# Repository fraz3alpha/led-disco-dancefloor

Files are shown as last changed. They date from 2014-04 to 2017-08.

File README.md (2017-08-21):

# led-disco-dancefloor

Welcome to the LED Disco Dance Floor project!

As seen at:

- Oggcamp 2017
- LJC Mad Scientists 2016

## Overview

The dancefloor project was conceived, as all good ideas are, at the pub.
The plan was to create a fully illuminated dancefloor, as a surpise, for the
wedding of two of my good friends; Gav & Anna.

The timeline from conception (pub) to completion (wedding) was roughly 8 months
between July of 2013 and the wedding in February 2014. Ideas were bounced around,
rejected, reworked, costed, rejected, reworked, and reworked some more over the
summer, and construction began in earnest November, and continued for 3 solid
months.

The result was a dancefloor consisting of 432 illuminated tiles, each 6"x6" (
because wood comes in feet and inches) creating an usable dancing area of 12'x9'.
The dancefloor was split into 9 modules (for transportation reasons), each coming
in at 4'x3' and about 15kg.

Patterns were created via a connected laptop via the included python program
to be displayed on each module by an ATMega328 microcontroller & TLC5940 constant
current LED drivers.

## The Software

The python software is available in `software/controller/`, and can be run with
or without an attached dancefloor for demonstration and testing purposes.

The software makes use of the **pygame** library to read input from connected joypads
and keyboards, as well as draw the GUI and handle the framerate. If a dancefloor
is connected, **pyserial** is used to send the data at 1Mbps

## The PCB & Firmware

The PCB is relatively simple and is only concerned with the action of parsing
incoming data via a serial connection and displaying it on the 48 connected RGB
LEDs. An ATMega328 is used as the microcontroller, and 3xTLC5940 ICs are used
to drive 16 LEDs each. Each of the Red, Green, and Blue LEDs are strobed, and
the switching is handled via 3 p-channel MOSFETs.

The firmware is written to be flashed using the Arduino IDE for convenience, but
uses very few of the Arduino library convenience functions (`random()`, which is
used in the failsafe backup pattern, being the exception) as most of the tight
loop is highly optimised for speed.

## Power

The entire dancefloor runs off 5v, and requires a high current power supply -
roughly 2.5A per module. An old ATX power supply with all the 5v rails tied
together has proved very reliable.

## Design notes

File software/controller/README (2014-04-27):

To start the controller code run `python DDRPi.py`

To start it in test mode with no floor attached and no need to sort out a config file run with '--testmode'

To run with a specific plugin for testing/development purposes, specify it with --plugin, e.g. : --plugin=HlsTestVisualisationPlugin

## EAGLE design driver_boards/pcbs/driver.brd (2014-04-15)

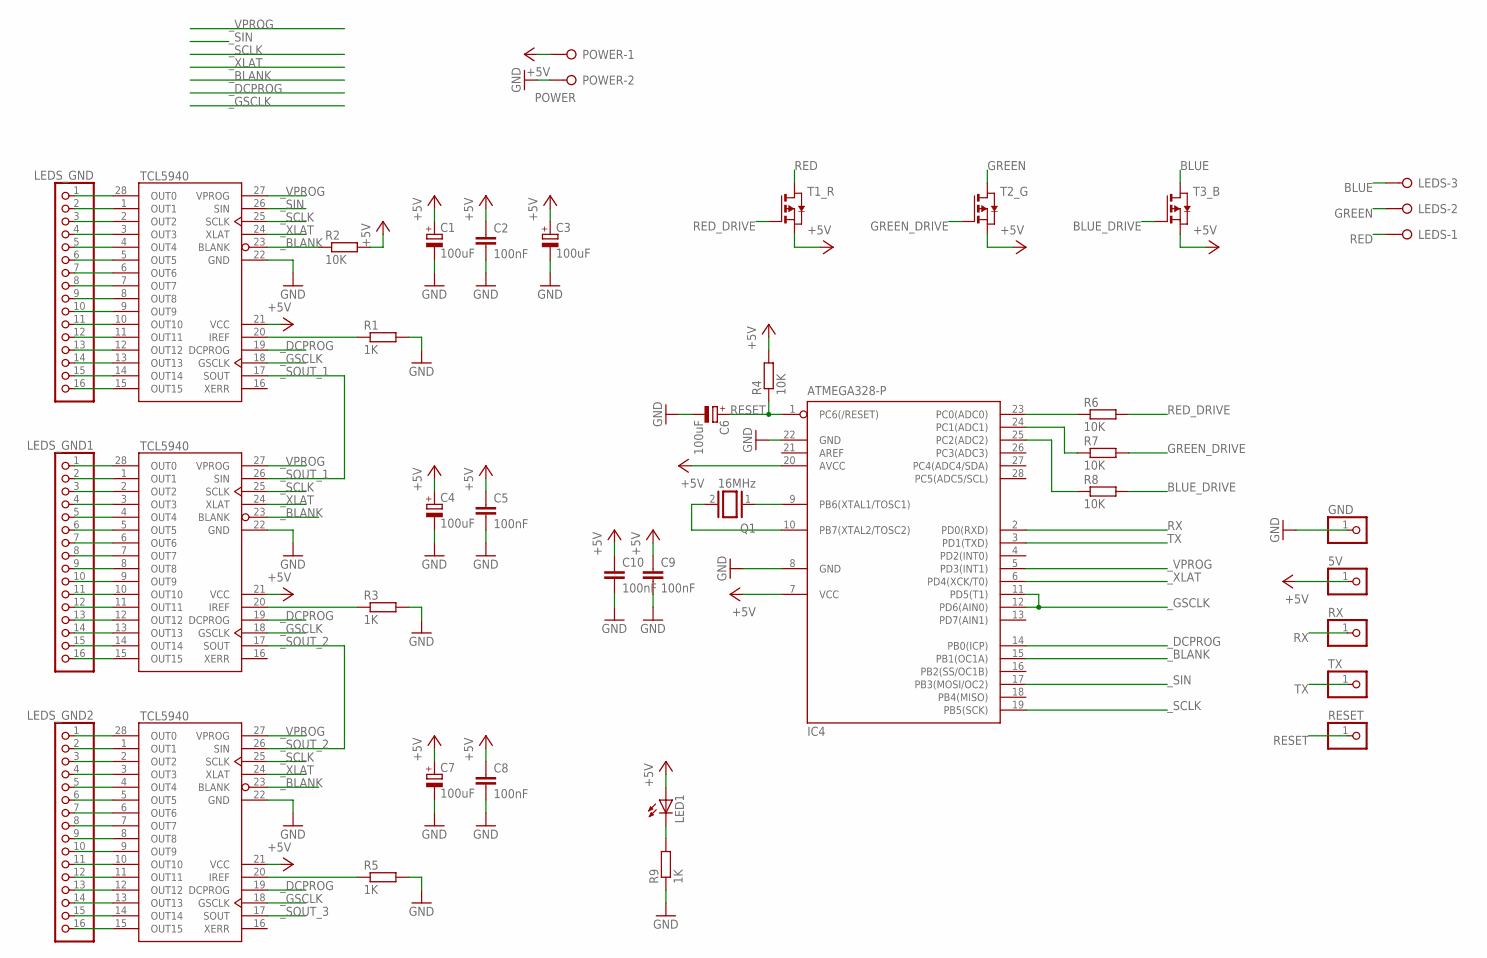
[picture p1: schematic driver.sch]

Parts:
5V: PINHD-1X1; 1X01
C1, C3, C4, C6, C7: 100uF; E2,5-6
C2, C5, C8, C9, C10: 100nF; C025-025X050
GND: PINHD-1X1; 1X01
IC4: ATMEGA328-P; DIL28-3
LED1: LED5MM
LEDS: W237-3E
LEDS_GND, LEDS_GND1, LEDS_GND2: PINHD-1X16; 1X16
POWER: POWER; W237-132
Q1: 16MHz; QS
R1, R3, R5, R9: 1K; M0805
R2, R4, R6, R7, R8: 10K; M0805
RESET: PINHD-1X1; 1X01
RX: PINHD-1X1; 1X01
T1_R, T2_G, T3_B: PMOSSOT23; SOT-23
TCL5940_1: TCL5940; DIP28
TLC5940_2, TLC5940_3: TCL5940; DIP28
TX: PINHD-1X1; 1X01

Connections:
+5V: 5V.1, C1.+, C2.1, C3.+, C4.+, C5.1, C7.+, C8.1, C9.1, C10.1, IC4.7 (VCC), IC4.20 (AVCC), LED1.A, POWER.1, R2.2, R4.2, T1_R.2 (S), T2_G.2 (S), T3_B.2 (S), TCL5940_1.21 (VCC), TLC5940_2.21 (VCC), TLC5940_3.21 (VCC)
BLUE: LEDS.3, T3_B.1 (D)
BLUE_DRIVE: R8.2, T3_B.3 (G)
GND: C1.-, C2.2, C3.-, C4.-, C5.2, C6.-, C7.-, C8.2, C9.2, C10.2, GND.1, IC4.8 (GND), IC4.22 (GND), POWER.2, R1.2, R3.2, R5.2, R9.1, TCL5940_1.22 (GND), TLC5940_2.22 (GND), TLC5940_3.22 (GND)
GREEN: LEDS.2, T2_G.1 (D)
GREEN_DRIVE: R7.2, T2_G.3 (G)
unnamed: R1.1, TCL5940_1.20 (IREF)
unnamed: LEDS_GND.1, TCL5940_1.28 (OUT0)
unnamed: LEDS_GND.2, TCL5940_1.1 (OUT1)
unnamed: LEDS_GND.3, TCL5940_1.2 (OUT2)
unnamed: LEDS_GND.4, TCL5940_1.3 (OUT3)
unnamed: LEDS_GND.5, TCL5940_1.4 (OUT4)
unnamed: LEDS_GND.6, TCL5940_1.5 (OUT5)
unnamed: LEDS_GND.7, TCL5940_1.6 (OUT6)
unnamed: LEDS_GND.8, TCL5940_1.7 (OUT7)
unnamed: LEDS_GND.9, TCL5940_1.8 (OUT8)
unnamed: LEDS_GND.10, TCL5940_1.9 (OUT9)
unnamed: LEDS_GND.11, TCL5940_1.10 (OUT10)
unnamed: LEDS_GND.12, TCL5940_1.11 (OUT11)
unnamed: LEDS_GND.13, TCL5940_1.12 (OUT12)
unnamed: LEDS_GND.14, TCL5940_1.13 (OUT13)
unnamed: LEDS_GND.15, TCL5940_1.14 (OUT14)
unnamed: LEDS_GND.16, TCL5940_1.15 (OUT15)
unnamed: R3.1, TLC5940_2.20 (IREF)
unnamed: LEDS_GND1.1, TLC5940_2.28 (OUT0)
unnamed: LEDS_GND1.2, TLC5940_2.1 (OUT1)
unnamed: LEDS_GND1.3, TLC5940_2.2 (OUT2)
unnamed: LEDS_GND1.4, TLC5940_2.3 (OUT3)
unnamed: LEDS_GND1.5, TLC5940_2.4 (OUT4)
unnamed: LEDS_GND1.6, TLC5940_2.5 (OUT5)
unnamed: LEDS_GND1.7, TLC5940_2.6 (OUT6)
unnamed: LEDS_GND1.8, TLC5940_2.7 (OUT7)
unnamed: LEDS_GND1.9, TLC5940_2.8 (OUT8)
unnamed: LEDS_GND1.10, TLC5940_2.9 (OUT9)
unnamed: LEDS_GND1.11, TLC5940_2.10 (OUT10)
unnamed: LEDS_GND1.12, TLC5940_2.11 (OUT11)
unnamed: LEDS_GND1.13, TLC5940_2.12 (OUT12)
unnamed: LEDS_GND1.14, TLC5940_2.13 (OUT13)
unnamed: LEDS_GND1.15, TLC5940_2.14 (OUT14)
unnamed: LEDS_GND1.16, TLC5940_2.15 (OUT15)
unnamed: R5.1, TLC5940_3.20 (IREF)
unnamed: LEDS_GND2.1, TLC5940_3.28 (OUT0)
unnamed: LEDS_GND2.2, TLC5940_3.1 (OUT1)
unnamed: LEDS_GND2.3, TLC5940_3.2 (OUT2)
unnamed: LEDS_GND2.4, TLC5940_3.3 (OUT3)
unnamed: LEDS_GND2.5, TLC5940_3.4 (OUT4)
unnamed: LEDS_GND2.6, TLC5940_3.5 (OUT5)
unnamed: LEDS_GND2.7, TLC5940_3.6 (OUT6)
unnamed: LEDS_GND2.8, TLC5940_3.7 (OUT7)
unnamed: LEDS_GND2.9, TLC5940_3.8 (OUT8)
unnamed: LEDS_GND2.10, TLC5940_3.9 (OUT9)
unnamed: LEDS_GND2.11, TLC5940_3.10 (OUT10)
unnamed: LEDS_GND2.12, TLC5940_3.11 (OUT11)
unnamed: LEDS_GND2.13, TLC5940_3.12 (OUT12)
unnamed: LEDS_GND2.14, TLC5940_3.13 (OUT13)
unnamed: LEDS_GND2.15, TLC5940_3.14 (OUT14)
unnamed: LEDS_GND2.16, TLC5940_3.15 (OUT15)
unnamed: LED1.K (C), R9.2
unnamed: IC4.9 (PB6(XTAL1/TOSC1)), Q1.1
unnamed: IC4.10 (PB7(XTAL2/TOSC2)), Q1.2
unnamed: IC4.23 (PC0(ADC0)), R6.1
unnamed: IC4.24 (PC1(ADC1)), R7.1
unnamed: IC4.25 (PC2(ADC2)), R8.1
RED: LEDS.1, T1_R.1 (D)
RED_DRIVE: R6.2, T1_R.3 (G)
RESET: C6.+, IC4.1 (PC6(/RESET)), R4.1, RESET.1
RX: IC4.2 (PD0(RXD)), RX.1
TX: IC4.3 (PD1(TXD)), TX.1
_BLANK: IC4.15 (PB1(OC1A)), R2.1, TCL5940_1.23 (BLANK), TLC5940_2.23 (BLANK), TLC5940_3.23 (BLANK)
_DCPROG: IC4.14 (PB0(ICP)), TCL5940_1.19 (DCPROG), TLC5940_2.19 (DCPROG), TLC5940_3.19 (DCPROG)
_GSCLK: IC4.11 (PD5(T1)), IC4.12 (PD6(AIN0)), TCL5940_1.18 (GSCLK), TLC5940_2.18 (GSCLK), TLC5940_3.18 (GSCLK)
_SCLK: IC4.19 (PB5(SCK)), TCL5940_1.25 (SCLK), TLC5940_2.25 (SCLK), TLC5940_3.25 (SCLK)
_SIN: IC4.17 (PB3(MOSI/OC2)), TCL5940_1.26 (SIN)
_SOUT_1: TCL5940_1.17 (SOUT), TLC5940_2.26 (SIN)
_SOUT_2: TLC5940_2.17 (SOUT), TLC5940_3.26 (SIN)
_SOUT_3: TLC5940_3.17 (SOUT)
_VPROG: IC4.5 (PD3(INT1)), TCL5940_1.27 (VPROG), TLC5940_2.27 (VPROG), TLC5940_3.27 (VPROG)
_XLAT: IC4.6 (PD4(XCK/T0)), TCL5940_1.24 (XLAT), TLC5940_2.24 (XLAT), TLC5940_3.24 (XLAT)

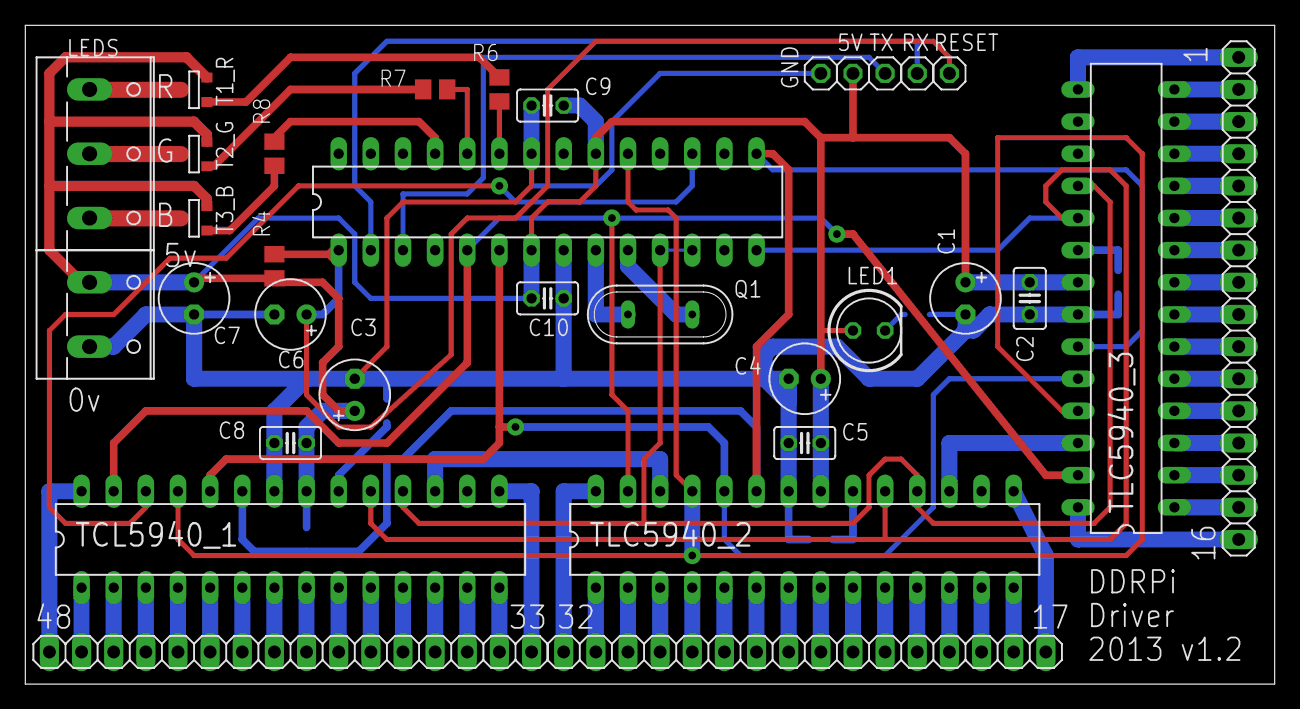
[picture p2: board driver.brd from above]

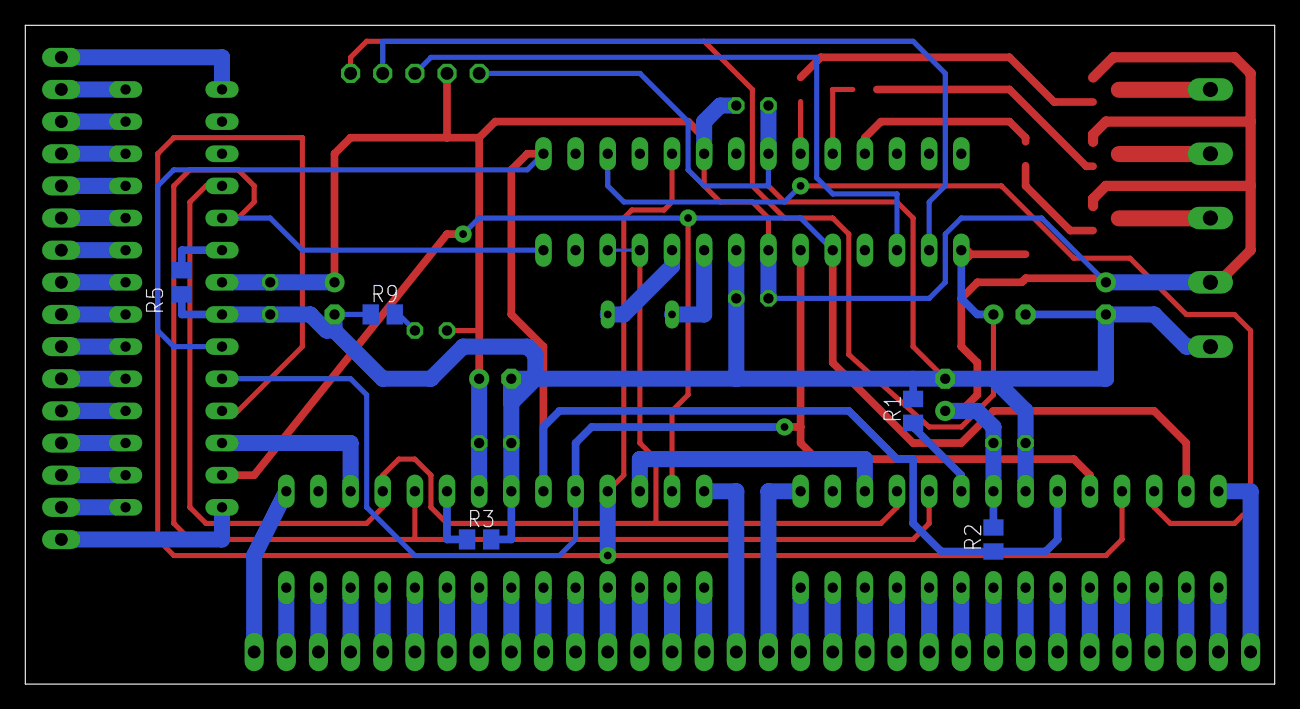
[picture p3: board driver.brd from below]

Board: 2 copper layers, 98.7 x 52.1 mm, 38 parts (5 on the bottom side), 77 nets.

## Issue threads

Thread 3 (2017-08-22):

Update documentation for python controller software

fraz3alpha, 2017-08-22:
The script has changed so much that the contents of various READMEs is completely wrong, and doesn't explain the current options for the script, e.g.
- No reference to playlists
- No explanation about how to write or use a new visualisation plugin
- No reference to joypad/keyboard controls

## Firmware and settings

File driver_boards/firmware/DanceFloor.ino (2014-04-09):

// AndyT's Dance Floor controller code. 
// Adapted from the original by solderlab.de

// One AVR drives 3 TLC5940 constant current LED drivers, for a total of 48 LEDs.
// LEDs are common cathode, with the TLC5940 connected to the cathode, and high side 
//  P-channel FETs providing the drive. 
// The FETs cycle RED/GREEN/BLUE along with changing TLC5940 data to give the illusion of
//  constant RGB colour when in fact only one is on at any given time.

// Data can be received from a PC through the serial port at 1000000 baud (1Mbps)

// If no data is received in several seconds then the module starts to set the LEDs to random
//  pure colours, changing 2 times a second

// Include the pgmspace header for storing the gamma correction tables
#include <avr/pgmspace.h>

// LEDs do not have a linear response curve, and particularly when they are driven by PWM.
// Here we have three curves to adjust the brightness to match human vision. 
// (Currently these are all identical, and follow an exponential curve, and need to be tuned)
PROGMEM prog_uint16_t exp_table_red[] =
{ 
  0,15,15,16,16,16,17,17,17,18,18,19,19,20,20,20,21,21,22,22,23,23,24,24,25,25,26,27,27,28,28,29,30,30,31,32,32,33,34,35,35,36,37,38,39,39,40,41,42,43,44,45,46,
  47,48,49,50,51,53,54,55,56,57,59,60,61,63,64,65,67,68,70,72,73,75,76,78,80,82,83,85,87,89,91,93,95,97,99,102,104,106,109,111,114,116,119,121,124,127,130,132,
  135,138,141,145,148,151,154,158,161,165,169,172,176,180,184,188,192,197,201,206,210,215,220,225,230,235,240,245,251,256,262,268,274,280,286,292,299,305,312,319,
  326,334,341,349,356,364,372,381,389,398,407,416,425,434,444,454,464,474,485,496,507,518,529,541,553,566,578,591,604,618,631,645,660,674,689,705,720,736,753,770,
  787,804,822,840,859,878,898,918,938,959,980,1002,1024,1047,1070,1094,1119,1143,1169,1195,1221,1249,1276,1305,1334,1364,1394,1425,1457,1489,1522,1556,1591,1626,
  1662,1699,1737,1775,1815,1855,1897,1939,1982,2026,2071,2117,2164,2212,2262,2312,2363,2416,2470,2524,2581,2638,2697,2757,2818,2881,2945,3010,3077,3146,3216,3287,
  3360,3435,3511,3590,3669,3751,3834,3920,4007,4095
};

PROGMEM prog_uint16_t exp_table_green[] =
{ 
  0,15,15,16,16,16,17,17,17,18,18,19,19,20,20,20,21,21,22,22,23,23,24,24,25,25,26,27,27,28,28,29,30,30,31,32,32,33,34,35,35,36,37,38,39,39,40,41,42,43,44,45,46,
  47,48,49,50,51,53,54,55,56,57,59,60,61,63,64,65,67,68,70,72,73,75,76,78,80,82,83,85,87,89,91,93,95,97,99,102,104,106,109,111,114,116,119,121,124,127,130,132,
  135,138,141,145,148,151,154,158,161,165,169,172,176,180,184,188,192,197,201,206,210,215,220,225,230,235,240,245,251,256,262,268,274,280,286,292,299,305,312,319,
  326,334,341,349,356,364,372,381,389,398,407,416,425,434,444,454,464,474,485,496,507,518,529,541,553,566,578,591,604,618,631,645,660,674,689,705,720,736,753,770,
  787,804,822,840,859,878,898,918,938,959,980,1002,1024,1047,1070,1094,1119,1143,1169,1195,1221,1249,1276,1305,1334,1364,1394,1425,1457,1489,1522,1556,1591,1626,
  1662,1699,1737,1775,1815,1855,1897,1939,1982,2026,2071,2117,2164,2212,2262,2312,2363,2416,2470,2524,2581,2638,2697,2757,2818,2881,2945,3010,3077,3146,3216,3287,
  3360,3435,3511,3590,3669,3751,3834,3920,4007,4095
};

PROGMEM prog_uint16_t exp_table_blue[] =
{ 
  0,15,15,16,16,16,17,17,17,18,18,19,19,20,20,20,21,21,22,22,23,23,24,24,25,25,26,27,27,28,28,29,30,30,31,32,32,33,34,35,35,36,37,38,39,39,40,41,42,43,44,45,46,
  47,48,49,50,51,53,54,55,56,57,59,60,61,63,64,65,67,68,70,72,73,75,76,78,80,82,83,85,87,89,91,93,95,97,99,102,104,106,109,111,114,116,119,121,124,127,130,132,
  135,138,141,145,148,151,154,158,161,165,169,172,176,180,184,188,192,197,201,206,210,215,220,225,230,235,240,245,251,256,262,268,274,280,286,292,299,305,312,319,
  326,334,341,349,356,364,372,381,389,398,407,416,425,434,444,454,464,474,485,496,507,518,529,541,553,566,578,591,604,618,631,645,660,674,689,705,720,736,753,770,
  787,804,822,840,859,878,898,918,938,959,980,1002,1024,1047,1070,1094,1119,1143,1169,1195,1221,1249,1276,1305,1334,1364,1394,1425,1457,1489,1522,1556,1591,1626,
  1662,1699,1737,1775,1815,1855,1897,1939,1982,2026,2071,2117,2164,2212,2262,2312,2363,2416,2470,2524,2581,2638,2697,2757,2818,2881,2945,3010,3077,3146,3216,3287,
  3360,3435,3511,3590,3669,3751,3834,3920,4007,4095
};

// Port and constant definitions for driving the TLC5940 ICs

//Gray Scale Depth for the PWM on TLC5940
#define Gray_Scale_Depth 4095

//GSCLK an PD6 (Arduino Pin 6)
#define GSCLK_Low       PORTD &=  ~(1 << 6)
#define GSCLK_High      PORTD |=   (1 << 6)

//XLAT an PD4 (Arduino Pin 4)
#define XLAT_Low       PORTD &=  ~(1 << 4)
#define XLAT_High      PORTD |=   (1 << 4)

//GSCK an PD5 (Arduino Pin 5)
#define GSCK_Low       PORTD &=  ~(1 << 5)
#define GSCK_High      PORTD |=   (1 << 5)

//VPRG an PD3 (Arduino Pin 3)
#define VPRG_Low       PORTD &=  ~(1 << 3)
#define VPRG_High      PORTD |=   (1 << 3)

//BLANK an PB1 (Arduino Pin 9)
#define BLANK_Low       PORTB &=  ~(1 << 1)
#define BLANK_High      PORTB |=   (1 << 1)

//SCLK an PB5 (Arduino Pin 13)
#define SCLK_Low       PORTB &=  ~(1 << 5)
#define SCLK_High      PORTB |=   (1 << 5)

//MOSI an PB3 (Arduino Pin 11)
#define MOSI_Low       PORTB &=  ~(1 << 3)
#define MOSI_High      PORTB |=   (1 << 3)

//Debug an PD7 (Arduino Pin 7)
#define Debug_Low       PORTD &=  ~(1 << 7)
#define Debug_High      PORTD |=   (1 << 7)

// The character that indicates new data has been received.
//  (This is effectively a 'sync' pulse)
# define CMD_NEW_DATA 1

// Module size constants

#define MODULE_WIDTH 6
#define MODULE_HEIGHT 8
#define RGB_LEDS MODULE_HEIGHT * MODULE_WIDTH
#define BUFFER_SIZE MODULE_WIDTH*MODULE_HEIGHT*3

// temporary and live display buffers
unsigned char display_buffer_1[BUFFER_SIZE];
unsigned char display_buffer_2[BUFFER_SIZE];

static unsigned char *offscreen_display_buffer = display_buffer_1;
static unsigned char *display_buffer = display_buffer_2;

// Variables used in the UART ISR
static unsigned char *ptr;
static unsigned int pos = 0;

// Temporary buffer to store the next set of random colours
//  (These are calculated in advance over a period of cycles
//   so that they do not take too much processing time)
unsigned char random_colours_buffer[BUFFER_SIZE];
unsigned int random_colours_buffer_pixel = 0;


volatile byte display_buffer_live = 1;

// Variables that keep track of state in the ISR and main loop
volatile byte new_row = 0;
volatile byte need_xlat = 0;
byte row = 0;

// Variables used to decide when we should switch to the backup
//  random pattern
unsigned long tickcounter = 0;
unsigned long lastdata_tickcounter = 0;
// 40000 = 20 seconds
unsigned long timeout = 4000;

volatile boolean cycling = false;
// 1000 ~ 1/2 second
unsigned long cycle_period = 500;
unsigned long cycle_tickcounter = 0;

// The 'pure' colours that are used during random cycling
unsigned long colours[] = {
  0xFF0000, 0x00FF00, 0x0000FF, 0xFFFF00, 0x00FFFF, 0xFF00FF, 0xFFFFFF};
int colours_length = 7;

void set_initial_pattern(void) {
  set_random_colours();
}

void set_random_colours() {

  for (int pixel=0; pixel < RGB_LEDS; pixel++) {
    unsigned long colour = colours[random(colours_length)];
    display_buffer[pixel * 3 + 0] = colour & 0xFF;
    display_buffer[pixel * 3 + 1] = (colour >> 8 ) & 0xFF;
    display_buffer[pixel * 3 + 2] = (colour >> 16) & 0xFF;   
  }

}

// Configuration of the AVR registers for communication with external
//  peripherals
void setup()   
{               
  // Set pins as inputs or outputs
  // Setup the SPI connection pins and the TLC5940 BLANK signal on PORTB
  DDRB |= (1<<1)  | (1<<2)  | (1<<3) | (1<<5) ; // BLANK, SS, MOSI, SCLK as OUTPUTS
  // Setup the remainder of the TLC5940 signal pins on PORTD
  DDRD |= (1<<3)  | (1<<4) |  (1<<6) | (1<<7) ; // VPRG, XLAT, GSCLK, Debug as OUTPUTS
  // PORTC is used to cycle the row high-side MOSFETS, and although only 
  //  pins 0, 1 & 2 are used, set them all as outputs
  DDRC = 255;

  // Configure the initial state of the TLC5940 control lines
  XLAT_Low;
  BLANK_High;
  VPRG_Low;
  Debug_Low;

  // Set an initial random patter in the display buffer
  set_initial_pattern();

  // Set Timer 1 (16bit) in count (capture) mode to count the number of output pulses up to the 
  //  greyscale depth. This then triggers an ISR to say that this LED has completed it's 
  //  cycle and to move on to the next row
  TCCR1A  = (1<<WGM11) | (0<<WGM10);            // Fast PWM with ICR1 as top
  TCCR1B  = (1<<WGM13) | (1<<WGM12);            // Fast PWM with ICR1 as top
  TCCR1B |= (1<<CS12)  | (1<<CS11) | (1<<CS10); // external clock (T1) on rising egde
  TIMSK1 |= (1<<TOIE1);                         // enable overflow interupt
  ICR1    = Gray_Scale_Depth;                   // Grey scale depth for TLC-PW

  // Set Timer 0 (8bit) to output a PWM pulse (which is then externally routed into Timer 1),
  //  which provides the clock source for the TLC5940 ICs.
  // It is not set as fast as possible because that leaves too much processing for the AVR
  //  to do, instead it is set a notch back (half speed)
  TCCR0A  = (1<<WGM01) | (0<<WGM00);            // CTC
  TCCR0A |= (0<<COM0A1) | (1<<COM0A0);          // Toggle on Compare Match
  TCCR0B  = (0<<CS02) | (0<<CS01) | (1<<CS00);  // No Prescaler
  // 0x00 is a bit too quick if you want to do any other processing,
  //  such as put in random pixels as well as receive data from the
  //  serial port, so put it up to 0x01. This makes the on time of 
  //  each colour 1ms, so a complete cycle in 3ms, which is still 
  //  strobing all colours at > 300Hz, so lots of time to play with
  OCR0A   = 0x01;                                  // f(OCR) = F_CPU/2/Prescaler

  // Configure the UART to receive data at 1 Mb/s
  UCSR0A |= (1<<U2X0);                                 // Double up UART
  UCSR0B |= (1<<RXEN0)  | (1<<TXEN0) | (1<<RXCIE0);    // UART RX, TX und RX Interrupt enable
  UCSR0C |= (1<<UCSZ01) | (1<<UCSZ00)             ;    // Asynchrous 8N1 
  UBRR0H = 0;
  UBRR0L = 1; //Baud Rate 1 MBit   --> 0% Error at 16MHz :-)

  // Enable global interrupts
  sei();

  // Configure and enable SPI  
  SPCR = (1<<SPE)|(1<<MSTR);  
  SPSR = B00000000;   

  // Double buffering doesn't work yet
  /*ptr=display_buffer_2;
   display_buffer = display_buffer_1;
   display_buffer_live = 1;
   */
  //  ptr = display_buffer;
  // Set the incoming data pointer to the start of the main display buffer
  ptr = display_buffer;

  // Prepopulate the random colour buffer
  if (random_colours_buffer_pixel < RGB_LEDS) {
    unsigned long colour = colours[random(colours_length)];
    random_colours_buffer[random_colours_buffer_pixel * 3 + 0] = colour & 0xFF;
    random_colours_buffer[random_colours_buffer_pixel * 3 + 1] = (colour >> 8 ) & 0xFF;
    random_colours_buffer[random_colours_buffer_pixel * 3 + 2] = (colour >> 16) & 0xFF; 
    random_colours_buffer_pixel++;
  } 

}

// If double buffering worked, we might use this, but it doesn't at the moment
void flip_buffers() {
  if (display_buffer_live == 1) {
    display_buffer_live = 2;
    display_buffer = display_buffer_2;
    ptr = display_buffer_1;
  } 
  else {
    display_buffer_live = 1;
    display_buffer = display_buffer_1;
    ptr = display_buffer_2;
  }
  lastdata_tickcounter = tickcounter;
  cycling = false;

}

// Main loop
void loop()        
{     
  // The loop does nothing until a new set of data needs to be shifted out for the next LED.
  // Everything else is handled by interrupts.
  if (new_row)
  {    
    shift_out_data(row);

    need_xlat = 1;

    new_row = 0;   
    
    // Every time there is a new row we increment our tick counter, which is our way of keeping
    //  track of time periods of the order of seconds, and we use this to cycle random colours
    //  at 1-4Hz. 2Hz is a pleasing cycling pattern.
        tickcounter++;

    // When we are cycling it can take a while to call random(), so lets do this once per loop.
    // If this is called many times in succession (e.g. 48), then you get a blip on the LED
    //  where it presumably should be sending more data (e.g. the xlat thing), but it isn't, so
    //  it does nothing, or something it shouldn't. either way, it's noticeable
    if (random_colours_buffer_pixel < RGB_LEDS) {
      unsigned long colour = colours[random(colours_length)];
      random_colours_buffer[random_colours_buffer_pixel * 3 + 0] = colour & 0xFF;
      random_colours_buffer[random_colours_buffer_pixel * 3 + 1] = (colour >> 8 ) & 0xFF;
      random_colours_buffer[random_colours_buffer_pixel * 3 + 2] = (colour >> 16) & 0xFF; 
      random_colours_buffer_pixel++;
    } 

    // If we are cycling, then see if we need to cycle again
    if (cycling == true) {

      if (tickcounter - cycle_tickcounter > cycle_period) {
        // Copy the current random colour buffer into the live display buffer
        // (TODO: If we had double buffering, we could just switch a pointer)
        memcpy(display_buffer, random_colours_buffer, BUFFER_SIZE);
        random_colours_buffer_pixel = 0;
        cycle_tickcounter = tickcounter;
      }
    } 
    else {
      // If we aren't cycling, then see if we need to start
      if (tickcounter - lastdata_tickcounter > timeout) {
        cycling = true;
      }
    }

  }
}

// Timer interupt for the TLC5940 clock input signal. Once this overflows we have 
//  completed the PWM cycle for the LEDs, and we should move onto the next row.
ISR( TIMER1_OVF_vect )
{  

  if (need_xlat)
  {
    XLAT_High;
    XLAT_Low;
    need_xlat = 0;
  }

  PORTC = ~(1<<row);

  BLANK_High; 
  BLANK_Low;

  // Move through the rows
  row++;
  if (row == 3) {
    row = 0;
  }
  new_row = 1;

  // Confirm we have handled the interrupt, clear the flag.
  TCNT1 = 0;
}

// UART interrupt for receiving data from a controlling computer.
ISR(USART_RX_vect) 
{
  // Read the data out of the UART RX memory location
  unsigned char b;
  b=UDR0;

  // If it is a frame sync pulse...
  if (b == CMD_NEW_DATA)  {
    // ... retransmit the pulse to subsequent modules
    UDR0=b; 
    //pos=0; 
    // Reset our counter
    pos=BUFFER_SIZE; 

    /*  
     if (offscreen_display_buffer == display_buffer_1) {
     offscreen_display_buffer = display_buffer_2;
     display_buffer = display_buffer_1;
     } else {
     offscreen_display_buffer = display_buffer_2;
     display_buffer = display_buffer_1;     
     }
     
     ptr=offscreen_display_buffer;
     */
    // And reset out buffer pointer location back to the start
    ptr=display_buffer;
    // Flip buffers to make the live one the one we have just populated, 
    //  and the temporary one containing incoming data, the other one
    //flip_buffers();

    // Make a note of when we last had a new frame - we use this to start
    //  the counter going to see if we should switch to random cycling
    lastdata_tickcounter = tickcounter;
    cycling = false;
    return;
  }    
  //  if (pos == BUFFER_SIZE) {
  // If we have received all the data we need (and have not yet received a new frame pulse),
  //  then relay the data to the next module by re-transmitting it.
  // This is a good way to keep signal integrity as each module is only receiving data from 
  //  the adjacent module in the chain, not from miles away where signal attenuation might be
  //  a problem
  if (pos == 0) {
    UDR0=b; 
    return;
  }
  // If we are still filling up our buffer, then store the data and keep track of how many
  //  piece of data we have had (so that we know when to stop)
  else {
    *ptr=b; 
    ptr++; 
    pos--;
  }  
}

// Shift out data to the TLC5940 ICs via the most efficient way possible: high speed SPI
void shift_out_data(byte row)
{

  // Get the appropriate gamma correction curve for this colour/row
  prog_uint16_t * exp_table;
  switch (row){ 
  case 2:
    exp_table = exp_table_blue;
    break;
  case 1:
    exp_table = exp_table_green;
    break;
  case 0:
  default:
    exp_table = exp_table_red;
    break;        
  }

  //Shift Out Data
  for(byte i = 0; i<24; i++)
  {
    unsigned int index = 6*(i) + row;
    unsigned int t1 = pgm_read_word_near(exp_table + display_buffer[index + 3]);
    unsigned int t2 = pgm_read_word_near(exp_table + display_buffer[index]);

    byte d1 = (highByte(t2) << 4) | (lowByte(t2) >> 4);
    spi_transfer(d1);

    byte d2 = (lowByte(t2) << 4) | (highByte(t1));
    spi_transfer(d2);

    byte d3 = (lowByte(t1)); 
    spi_transfer(d3);      
  }
  
}

// SPI transmission function
void spi_transfer(byte data)
{
  SPDR = data;	  // Start the transmission
  while (!(SPSR & (1<<SPIF)))     // Wait the end of the transmission
  {
  };
}

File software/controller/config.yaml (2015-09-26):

# Main option config
system:
  plugin_dir: plugins
  floor: True
  tty: /dev/ttyUSB0
  debug: False
  debug_logging: True
  pipe: /tmp/dance_pipe
  floor_rotation: 2

  filters:
    1:
        name: ClearFilter
#    2:
#        name: NegativeFilter
    3:
        name: NeutralDensityFilter
        factor: 1

outputs:
  1:
    name: dancefloor serial
    type: serial
    tty: /dev/ttyUSB0
    baud: 1000000
    enabled: True

  2:
    name: dancefloor gui
    type: gui
    enabled: True

  3:
    name: dancefloor pipe
    type: pipe
    pipe: /tmp/dance_pipe
    enabled: False

# Module layout config (we may change this later)
modules:
  3:
    width: 6
    height: 8
    x_position: 0
    y_position: 0
    orientation: W

  2:
    width: 6
    height: 8
    x_position: 0
    y_position: 6
    orientation: E

  1:
    width: 6
    height: 8
    x_position: 0
    y_position: 12
    orientation: W

  6:
    width: 6
    height: 8
    x_position: 8
    y_position: 12
    orientation: W
    
  5:
    width: 6
    height: 8
    x_position: 8
    y_position: 6
    orientation: W
    
  4:
    width: 6
    height: 8
    x_position: 8
    y_position: 0
    orientation: E
    
  9:
    width: 6
    height: 8
    x_position: 16
    y_position: 0
    orientation: W
    
  8:
    width: 6
    height: 8
    x_position: 16
    y_position: 6
    orientation: E
    
  7:
    width: 6
    height: 8
    x_position: 16
    y_position: 12
    orientation: E

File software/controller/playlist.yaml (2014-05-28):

plugins:

  -
    name: DiscoFloorVisualisationPlugin
    duration: 60
    square_size: 2
    fps: 2
    colour_set: secondary

  -
    name: SpeedingBlobsVisualisationPlugin
    duration: 30

  -
    name: PatternsVisualisationPlugin
    duration: 30
    patterns:
      - Explode 2.1

  -
    name: SpinningWheelVisualisationPlugin
    duration: 30
    colours: full_colour

  -
    name: ScrollingTextVisualisationPlugin
    duration: 10
    text: Congratulations
    speed: 25
    background_colour: black
    colour: red

  -
    name: FireworksVisualisationPlugin
    mode: fireworks
    duration: 30

  -
    name: LoveHeartVisualisationPlugin
    duration: 30
    upper_name: Phil
    lower_name: Naomi

  -
    name: PatternsVisualisationPlugin
    duration: 30
    patterns:
      - Nyan Cat

  -
    name: DiscoFloorVisualisationPlugin
    duration: 60
    square_size: 2
    fps: 2
    colour_set: secondary

  -
    name: SoundToLightVisualisationPlugin
    duration: 60
    policy: exp
    mode: latest

  -
    name: WavyBlobVisualisationPlugin
    duration: 30

  -
    name: SpinningWheelVisualisationPlugin
    duration: 20
    speed: 30
    colours: black_and_white
  -
    name: SineWaveVisualisationPlugin
    duration: 30
    background_colour: red
    colour: white
    amplitude: 8.0

  -
    name: DiscoFloorVisualisationPlugin
    duration: 60
    square_size: 2
    fps: 2
    colour_set: secondary

  -
    name: SoundToLightVisualisationPlugin
    duration: 30
    policy: exp
    mode: scrolling

  -
    name: FireworksVisualisationPlugin
    mode: explosions
    duration: 30

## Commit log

2014-04-04 Initial commit of Firmware
    Initial firmware based on the code from solderlab.de
    with various changes , including pins used, number of
    columns strobed, and generation of random patterns
    when there is no input data
2014-04-04 Eliminate LED flicker when cycling through colours
    Closes #1 - whereby LEDs have a noticeable flicker when cycling
    through the random colours.
    - Move the call to random() so that it is called at most once
    per loop, and that the time take to calculate new values is
    spread out, reducing the time paused when creating a new
    set of pixel colours
2014-04-04 Move controller code to its own directory
    Created software/controller to contain the code that
    drives the floor so that it isn't mixed in with other
    resources such as design documentation, firmware etc..
    [diamond.csv, explode.csv, explode2.csv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]
2014-04-09 Fixed random flickering bug when received data via UART
    Previously the LEDs would flash everytime a new frame
    was received due to insufficient processing time being
    available.
    I have increased the time between switching between each
    LED colour (effectively doubled) from a on time of ~ 0.5ms
    to 1ms. This reduces the amount of time spent in interrupt
    routines, and also sending data to the TLC5940 driver ICs
    Additionally I have increased the number of comments in
    the code, and credited solderlab.de for the orignal version
    There is also a different gamma correction curve available
    for each colour should we find the time to calibrate it.
    [DanceFloor.ino]
2014-04-15 Initial check-in of PCB eagle & gerber files
    Version 1.2 of the PCB
    - Eagle project, board and schematic files
    - Gerber files for board production
    - gerber view project file for viewing gerbers
    [driver.brd, driver.sch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]
2014-04-27 Updated python code to the V2 work in progress
    - Including:
    New playlist mechanism for automatic cycling of plugins
    Multiple plugin directories (currently hard coded)
    --testmode for those without a floor, and who don't want
    to mess around with config files
    A nice GUI to show what is going on (can be disabled
    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
    [diamond.csv, explode.csv, explode2.csv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]
2014-04-27 Resolve path of relative plugin directories relative to root
    - Change the way the plugin directories are resolved,
    instead of being relative to the current working
    directory they are now relative to the root of
    the main DDRPi script, meaning that it can be invoked
    from anywhere, no longer just in the root directory
2014-04-27 Add initial version of the patterns plugin
    - Ported the existing PatternsVisualisationPlugin
    to the new format and added a directory of its
    own to store the various CSV files in
    [explodeA.csv, knightRider.csv, matrix.csv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]
2014-04-27 Change print calls to print() calls where necessary
2014-04-27 Add logger and remove reference to print()
    - Removed reference to print(), with all text output now
    being handled by a Logger, set by default to Info level
2014-04-27 Switch dict.iteritems() to .items() for python 3
    - .iteritems() was removed in python 3, so switch to using
    .items() which is just as good for our usage
2014-04-27 Switch to use standard logging
    - My logger clashed with the built-in one, so switch to using that
2014-04-28 Add basic keyboard > joystick button mapping
    - Enable testing of plugins that take input without connected
    joypads by mapping keyboard input events to joystick events
    - Renamed handle method in DiscoFloor plugin so that it receives
    events
2014-04-28 Exit when we hit the close button in the GUI
2014-04-28 Refactor DiscoFloor Plugin to run at a higher framerate
    - The DiscoFloorVisualisationPlugin now runs at 25fps,
    but still only updates the colours at the specified
    rate. This means that input events are taken off the
    queue in a more timely manner, and the input feels
    more responsive
2014-04-28 Add PipeOutput class
    - Add pipe output class, and refactor it and the SerialOutput
    to have a common superclass as they both perform the
    conversion logic
    - Add sample config stanza for the PipeOutput
    - Add an initial checkin of the FloorSimulator code
    - Add a method to the layout to determine the correct order to
    output the pixels for the dancefloor
    [config.yaml]
2014-04-28 Added --playlist option, and configurable plugins
    - A playlist can now be passed in on the command line using
    the --playlist argument.
    - A playlist is a yaml file consisting of a list of plugins
    in the playlist, and any configuration options for them.
    All plugins support the duration: attribute, and it is
    a time given in seconds
    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
2014-05-03 Initial commit of spinning wheel plugin
    - Like the Mac OS spinngin wheel of death, it cycles
    around, varying the hue as it goes
2014-05-03 Hide time remaining value in GUI when plugin doesn't auto advance
    - When the playlist doesn't automatically move to the next plugin
    the time remaining doesn't make any sense, so hide that
    bit of information in the case that auto_advance is false
2014-05-06 Hardened calling plugin frame drawing methods
    - Added try: except: around calling plugin .draw_frame()
    and .draw_splash()
    - In case of failure, draw a default message - currently
    a red screen of death
    - Also change the menu scrolling code to draw a bar, not
    the arrows as previously
2014-05-10 Add d-pad events to the ControllerInput class
    - Map the d-pad buttons to keys on the keyboard
2014-05-18 Catch exceptions loading plugins and skip them
    - In the case where a plugin can't be loaded for any reason
    (e.g. a dependent module is not available, or there is a
    syntax error), then skip over that plugin
    Fixes #10
2014-05-18 Make the wheel full brightness
    - The wheel was half brightness because I hadn't realised
    HSV and HSL colour spaces weren't the same
2014-05-18 Print error when the plugin can't draw a frame
2014-05-20 Initial commit of Camera streaming plugin
    - Doesn't have a lot of use, but see the world in
    highly pixelated form! On your dance floor!
2014-05-24 Redid blob colour code to avoid discontinuity when the hue rolls over
    - Switch the mode of operation so that the blobs are always added to the
    the background hue, rather than separate from it.
2014-05-24 Add floor rotation functionality
    - The floor output can be rotate by adding
    system:floor_rotation: 0|1|2|3
    to the config file. Each increment rotates the floor output
    by 90 degrees
    Fixes #2
    [config.yaml]
2014-05-24 Added multiple camera selection
    - Press Right Bumper to iterate over any connected cameras
2014-05-25 Added explosion option
    - Along side fireworks, just general random explosions
    can now also be shown. Switchable with LB, or a config
    parameter
2014-05-27 Add text customisations
    - In order to display some names on the Love Heart plugin we
    need to shorten some of the letters. Here werovide a mechanism
    to pass in the character definitions so that we can draw
    whatever seems reasonable.
    - Add two specific text drawing functions for Naomi and Phil
    - Add the Phil & Naomi message to the playlist
    [playlist.yaml]
2014-05-28 Made Patterns plugin configurable
    - Taken the existing pattern configurations and added them into
    and internal repository, so that they can be selected from
    by appropriate configuration in a playlist. In the absence of
    any specific patterns listed, all the patterns are added
    - Also added a couple of patterns to the sample playlist
    Fixes #13
    [diamond.csv, explode.csv, explode2.csv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]
2014-05-28 Fixed #12 - Tetris crash when UP is the first button pressed
    - Pressing UP as the first button failed because the repeat_axis
    wasn't set up for buttons that had no effect. We now skip
    past the check if we haven't set the axis
2015-09-26 Added moving centre to SpinningWheel plugin, and corrected indentation
    - Corrected indentation to spaces not tabs, so everything appears to have changed
    - Added ability to switch the mode to a moving 'centre', i.e. the spinning
    appears to centre just of the edge of the floor, and it moves around the edge,
    giving the appearance of different pattern shapes
    - Added controller inputs to change the mode and colours at runtime
2015-09-26 Added initial filter support to Serial Output
    - Now we can add filters to the output getting sent to the serial port,
    initially:
    ClearFilter
    NegativeFilter
    NeutralDensityFilter
    - Filters configured in config.yaml in system > filters
    - This means that in the future we will be able to correct for the LEDs
    not matching the expected colours (as seen on the screen) in the software
    [config.yaml]
